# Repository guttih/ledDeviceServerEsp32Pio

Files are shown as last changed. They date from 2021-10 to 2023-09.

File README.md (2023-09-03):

# ledDeviceServerEsp32Pio
An application running on esp32 which controls a addressable light strip using
the [fastLed] library.  Supported strips are WS2811, WS2801 and  APA102.

A new program can be uploaded over the air (OTA) and controlled using [VoffCon].

## Pins
__GPIO16__ is connected to DI or Data on the strip and if the strip has
a clock pin then __GPIO17__ is connected to thi CL or Clock pin.

Some older projects use the GPIO13 and GPIO14 pins, but these pins ADC2 which
are used by the Wifi library and should not be used with wifi. 

## Development

For information intended for development of this project can be found in the
[development.adoc](docs/development.adoc) document.

[fastLed]: https://fastled.io/
[VoffCon]: http://voffcon.com/

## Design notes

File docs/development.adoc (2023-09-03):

= Development

This document contains information to help with the development of this project.

https://platformio.org/?utm_source=platformio&utm_medium=piohome[Platform IO] with the https://github.com/espressif/arduino-esp32[Arduino core for the ESP32] is used to 
compile, build, test and send the application to the https://www.espressif.com/en/products/socs/esp32[Esp32] micro controller.

[options="header"]
|====
^|Esp32 ^|Platform IO
^a|
image::https://github.com/guttih/voffcon/blob/master/docs/images/esp32DevModule.PNG?raw=true[https://github.com/guttih/voffcon/blob/master/docs/images/esp32DevModule.PNG, 160,120,link=https://www.espressif.com/en/products/socs/esp32]

^a|
Platform IO
|====

== Testing

I selected the https://docs.platformio.org/en/latest/advanced/unit-testing/frameworks/unity.html[Unity test framework] to use with https://docs.platformio.org/en/latest/advanced/unit-testing/index.html[PlatformIO] for testing specific parts of the code.

.Important links
* link:https://docs.platformio.org/page/plus/unit-testing.html[PlatformIO Unit Testing]
* link:https://docs.platformio.org/en/latest/advanced/unit-testing/frameworks/unity.html[Unity test framework]

=== Getting started with testing

. Open the Arduino IDE application 
. Find out which comport the micro-controller is connected to
.. Hover over _Tools->Port_ and remember which _COM ports_ are connected
.. Connect your Esp32 micro-controller to a usb port
.. Hover over _Tools->Port_ and remember which _COM port_ was added +
   *For demonstration purposes* set's say the port *COM6* was added.
. Set the correct test port
.. Open the file link:../platformio.ini[platformio.ini]
.. Disable uploading via wifi and enable uploading via USB
...  Make sure to add  `;` in front of the lines _upload_port = orri_sign_ and _upload_protocol = espota_ 
... Make sure that the lines lines _upload_port = COM6_ and _test_port = COM6_
   exist under the _[env:esp32dev]_ section.
... That is something like this:
+
[shell-caption]
[source, shell]
----
[env:esp32dev]
; upload_port = orri_sign
; upload_protocol = espota
upload_port = COM6
test_port = COM6
----

==== Running the test

Assuming the esp32 is connected to the usb on port COM6
```
pio test -e esp32dev
```

Showing serial print monitor
```
pio test -e esp32dev -v
```

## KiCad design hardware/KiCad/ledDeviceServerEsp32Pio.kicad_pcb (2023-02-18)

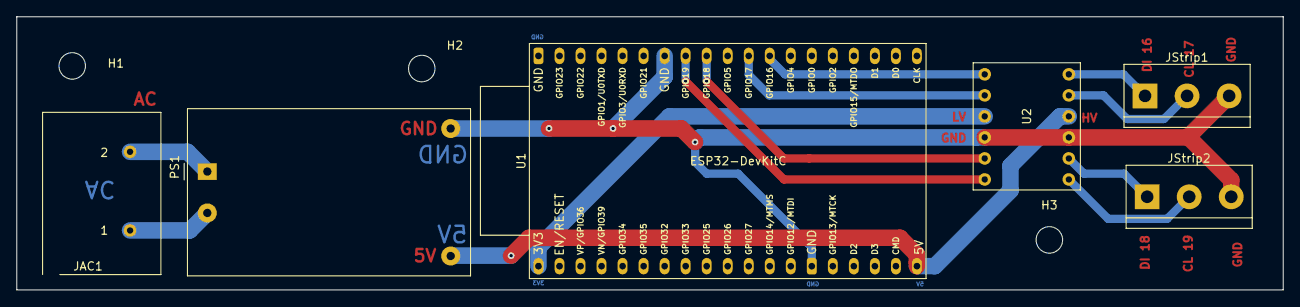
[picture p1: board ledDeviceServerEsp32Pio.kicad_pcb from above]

Board: 2 copper layers, 153.0 x 33.0 mm, 9 parts (0 on the bottom side), 13 nets.

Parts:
H1, H2, H3: MountingHole; MountingHole_3.2mm_M3
JAC1: Terminal_AC; Screw_Termianl_01x02
JStrip1, JStrip2: Terminal_LCDstrip; TerminalBlock_bornier-3_P5.08mm
PS1: HLK-PM01; Converter_ACDC_HiLink_HLK-PMxx
U1: ESP32-DevKitC
U2: LLC_4CH

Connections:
/CLOCK1: JStrip1.2, U2.7
/CLOCK2: JStrip2.2, U2.11
/DATA1: JStrip1.1, U2.5
/DATA2: JStrip2.1, U2.9
GND: JStrip1.3, JStrip2.3, PS1.3, U1.14, U1.32, U2.3
unnamed: JAC1.1, PS1.2
unnamed: JAC1.2, PS1.1
unnamed: PS1.4, U1.19, U2.2
unnamed: U1.1, U2.1
unnamed: U1.27, U2.4
unnamed: U1.28, U2.6
unnamed: U1.30, U2.8
unnamed: U1.31, U2.10

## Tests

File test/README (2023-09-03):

This directory is intended for PlatformIO Unit Testing and project tests.

Unit Testing is a software testing method by which individual units of
source code, sets of one or more MCU program modules together with associated
control data, usage procedures, and operating procedures, are tested to
determine whether they are fit for use. Unit testing finds problems early
in the development cycle.

More information about PlatformIO Unit Testing:
- https://docs.platformio.org/page/plus/unit-testing.html
- Testing this application (ledDeviceServerEsp32Pio) is described in the test section
  of the file [docs/development.adoc].

[docs/development.adoc]:../docs/development.adoc#testing

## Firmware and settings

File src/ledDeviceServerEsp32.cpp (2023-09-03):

/*
VoffCon is a system for controlling devices and appliances from anywhere.
It consists of two programs.  A "node server" and a "device server".
Copyright (C) 2016  Gudjon Holm Sigurdsson

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
You can contact the author by sending email to gudjonholm@gmail.com or
by regular post to the address Haseyla 27, 260 Reykjanesbar, Iceland.

    Program for Board: ESP32 Dev Module
*/

//Christmas lights: see: ali: https://www.aliexpress.com/item/32444415410.html?spm=a2g0s.9042311.0.0.27424c4dQ0AYL8  gparts: http://parts.guttih.com/parts/view/5bf9a0402e0e1a69a99a9bc9


//#define FASTLED_ALLOW_INTERRUPTS 0
//#define FASTLED_ESP32_FLASH_LOCK 1

/*
    To select the different strip devices you must add a define declaration
    to the file StripHelper.h
*/
#include "StripHelper.h"
#include "config.h"
#include "upload-ota.h"

#ifdef WS2811_RGB_DATA_PIN13
    const char* deviceId = "5dd9e66f67c66604d5daf0c0"; /*Hilmars ljós*/
     const char* hostName = "ws2811_strip"; /*max hostname 15 characters*/
    #define NUM_LEDS 50
    #define DATA_PIN 14  /*white wire  strip: http://parts.guttih.com/parts/register/5bf9a0402e0e1a69a99a9bc9*/
    #define STRIP_TYPE WS2811
    #define COLOR_SCHEME RGB
    StripHelper stripper;
#elif defined (CHRISTMAS_SOUTH)
    const char* deviceId = "615cabda61210d052212454d"; /*Christmas strip*/
    const char* hostName = "hilmar_strip"; /*max hostname 15 characters*/
    #define NUM_LEDS 382
    #define DATA_PIN 16  /*white wire  strip: http://parts.guttih.com/parts/view/5fa91941bff3fe05309547ee */
    #define STRIP_TYPE WS2811
    #define COLOR_SCHEME RGB
    StripHelper stripper;
#elif defined (SOLEY_IN)
    #include "StripSoley.h"
    const char* deviceId = "5c430cf9346ba80c6fe293a2"; /*Soley device*/
    const char* hostName = "soley_sign"; /*max hostname 15 characters*/
    #define NUM_LEDS 129
    #define STRIP_TYPE APA102
    #define COLOR_SCHEME BGR 
    #define CLOCK_PIN 13  
    #define DATA_PIN  14 
    StripSoley stripper; 
#elif defined (ORRI_IN)
    #include "StripOrri.h"
    const char* deviceId = "63f1253530dc6b0533d3659a"; /*Orri device*/
    const char* hostName = "orri_sign"; /*max hostname 15 characters*/
    #define NUM_LEDS 300
    #define STRIP_TYPE APA102
    #define COLOR_SCHEME BGR 
    #define CLOCK_PIN 16  
    #define DATA_PIN  17 
    StripOrri stripper; 
#elif defined (KITCHEN_ISLAND)
    const char* deviceId = "5d879b9ba02e5105340114d2"; /*Kitchen Iceland device*/    
     const char* hostName = "kitchen_island"; /*max hostname 15 characters*/
    #define NUM_LEDS 170
    #define STRIP_TYPE APA102
    #define COLOR_SCHEME BGR 
    #define CLOCK_PIN 13  /*yellow wire*/
    #define DATA_PIN  14  /*green wire*/   
    StripHelper stripper;
#else
    const char* deviceId = "5d177b6139d052053701e0af"; /*A normal strip*/
    const char* hostName = "expressif_hostN";
    #define NUM_LEDS 34 /*150 in a normal strip*/
    #define STRIP_TYPE WS2801
    #define COLOR_SCHEME RBG
    #define CLOCK_PIN 13  /*green wire*/
    #define DATA_PIN  14  /*blue wire*/ 
    StripHelper stripper;
#endif

#define BRIGHTNESS_DEVICE_PIN 15

CRGB leds[NUM_LEDS];




/*
    Board: ESP32 DEV Module
*/

// Name of the wifi (accesspoint)network
// example: "guttisWiFi"
#ifdef BLABLA
    const char* ssid = "TOTO";
#elif defined(CHRISTMAS_SOUTH)
    const char* ssid = "TOTO";
#else
    const char* ssid = "swingway"; /*This will be the default ssid used*/
#endif
// Wifi password
const char* password = getWifiPassword();
// port number which this device will be operating on.
// example: 5100
const int   PORT = 80;
// example: 6100
const int   voffconServerPort = 6100;

IPAddress

// ip address which this device will be operating on.
// Example: "192.168.1.158"     
myIp(192,168,1,238),

//the default gateway which this device will be operating on.
// example: "192.168.1.254"
gateway(192,168,1,1),

// the default gatway on this network.
// On windows goto command
// prompt and type "ipconfig"
// example: "255.255.255.0"
subnet(255,255,255,0),

// example: "192.168.1.127"
voffconServerIp(192,168,1,79);

/*boolean grantAccessToEverybody:
* Set to true if you want to allow all clients where the first 3 numbers
* in a client IP address are the same same as myIp (this server IP address).
.*/
boolean grantAccessToEveryone = false;

boolean grantAccessToAllClientsOnSameSubnet = true;
/*boolean grantAccessToFirstCaller:
* set to true if you want to allow the first client to call the "/setup" method
* to be automaticaly granted access.  that is, client IP address will be whitelisted.
.*/

WiFiServer server(PORT);

const int ERROR_NUMBER = -9999;

enum OBJECTTYPE {
    OBJECTTYPE_KEYVALUE_STRING,
    OBJECTTYPE_KEYVALUE_INT,
    OBJECTTYPE_PINS_ARRAY,
    OBJECTTYPE_PIN,
    OBJECTTYPE_PINS,
    OBJECTTYPE_DATE,
    OBJECTTYPE_WHITELIST_ARRAY,
    OBJECTTYPE_STATUS,
    OBJECTTYPE_LOG_PINS,
    OBJECTTYPE_INFORMATION,
    OBJECTTYPE_WARNING,
    OBJECTTYPE_ERROR,
    /*add next type above this line*/
    OBJECTTYPE_COUNT
};

enum JSONTYPEKEY {
    KEYVALUE_STRING,
    KEYVALUE_INT,
    KEYVALUE_DOUBLE
};

#ifndef CODE_BLOCK_LinkedList

//do not remove the comment below this line
//INSERT_FROM_HERE

//   ---------------------------------------------------------------
//  LinkedList.h - V1.1 - Generic LinkedList implementation
//  For instructions, go to https://github.com/ivanseidel/LinkedList

//  Created by Ivan Seidel Gomes, March, 2013.
//  Released into the public domain.
//   ---------------------------------------------------------------

template<class T>
struct ListNode
{
    T data;
    ListNode<T> *next;
};

/// <summary>
/// A general linked list ready to be used or Inherited
/// </summary>
template <typename T>
class LinkedList {

protected:
    int _size;
    ListNode<T> *root;
    ListNode<T> *last;

    // Helps "get" method, by saving last position
    ListNode<T> *lastNodeGot;
    int lastIndexGot;
    // isCached should be set to FALSE
    // everytime the list suffer changes
    bool isCached;

    ListNode<T>* getNode(int index);

public:
    /// <summary>
    /// The list constructor
    /// </summary>
    LinkedList();
    ~LinkedList();

    
    
    /// <summary>
    /// Returns current size of LinkedList
    /// </summary>
    /// <returns>a int number</returns>
    virtual int size();

    /// <summary>
    /// Adds a T object in the specified index;
    /// Unlinkand link the LinkedList correctly;
    /// Increment _size
    /// </summary>
    /// <param name="index">Where to add the object in the zero based index</param>
    /// <param name="T">The object to be added</param>
    /// <returns>Success: true.  Fail: false.</returns>
    virtual bool add(int index, T);

    /// <summary>
    /// Adds a T object in the end of the LinkedList;
    /// Increment _size;
    /// </summary>
    /// <param name="T">The object</param>
    virtual bool add(T);
    
    /// <summary>
    /// Adds a T object in the start of the LinkedList;
    /// Increment _size;
    /// </summary>
    /// <param name="T">The object to be added at beginning of list</param>
    /// <returns></returns>
    virtual bool unshift(T);

    /// <summary>
    /// Set the object at index, with T;
    /// Increment _size;
    /// </summary>
    /// <param name="index">Zero based index of where the object is</param>
    /// <param name="T">The object which values will be overwritten</param>
    /// <returns></returns>
    virtual bool set(int index, T);

    /// <summary>
    /// Remove object at index;
    /// If index is not reachable, returns false;
    /// else, decrement _size
    /// </summary>
    /// <param name="index"></param>
    /// <returns>Success: The object which was removed. Fail: an object created with the default constructor</returns>
    virtual T remove(int index);

    /// <summary>
    /// Remove last object;
    /// </summary>
    /// <returns>The data of the removed object</returns>
    virtual T pop();
    
    /// <summary>
    /// Remove first object;
    /// </summary>
    virtual T shift();
    
    /// /// <summary>
    /// Get the element at a specific index on the list;
    /// Return Element if accessible,
    /// else, return false;
    /// </summary>
    /// <param name="index">Zero based index if the object in the list</param>
    /// <returns>Success: the object.  Fail: A object created with a default constructor</returns>
    virtual T get(int index);

    /// <summary>
    /// Clear the entire array
    /// That is remove all objects from the list and delete them from memory
    /// </summary>
    virtual void clear();
};

// Initialize LinkedList with false values
template<typename T>
LinkedList<T>::LinkedList()
{
    root = NULL;
    last = NULL;
    _size = 0;

    lastNodeGot = root;
    lastIndexGot = 0;
    isCached = false;
}

// Clear Nodes and free Memory
template<typename T>
LinkedList<T>::~LinkedList()
{
    ListNode<T>* tmp;
    while (root != NULL)
    {
        tmp = root;
        root = root->next;
        delete tmp;
    }
    last = NULL;
    _size = 0;
    isCached = false;
}

/*
Actually "logic" coding
*/

template<typename T>
ListNode<T>* LinkedList<T>::getNode(int index) {

    int _pos = 0;
    ListNode<T>* current = root;

    // Check if the node trying to get is
    // immediately AFTER the previous got one
    if (isCached && lastIndexGot <= index) {
        _pos = lastIndexGot;
        current = lastNodeGot;
    }

    while (_pos < index && current) {
        current = current->next;

        _pos++;
    }

    // Check if the object index got is the same as the required
    if (_pos == index) {
        isCached = true;
        lastIndexGot = index;
        lastNodeGot = current;

        return current;
    }

    return NULL;
}

template<typename T>
int LinkedList<T>::size() {
    return _size;
}

template<typename T>
bool LinkedList<T>::add(int index, T _t) {

    if (index >= _size)
        return add(_t);

    if (index == 0)
        return unshift(_t);

    ListNode<T> *tmp = new ListNode<T>(),
        *_prev = getNode(index - 1);
    tmp->data = _t;
    tmp->next = _prev->next;
    _prev->next = tmp;

    _size++;
    isCached = false;

    return true;
}

template<typename T>
bool LinkedList<T>::add(T _t) {

    ListNode<T> *tmp = new ListNode<T>();
    tmp->data = _t;
    tmp->next = NULL;

    if (root) {
        // Already have elements inserted
        last->next = tmp;
        last = tmp;
    }
    else {
        // First element being inserted
        root = tmp;
        last = tmp;
    }

    _size++;
    isCached = false;

    return true;
}

template<typename T>
bool LinkedList<T>::unshift(T _t) {

    if (_size == 0)
        return add(_t);

    ListNode<T> *tmp = new ListNode<T>();
    tmp->next = root;
    tmp->data = _t;
    root = tmp;

    _size++;
    isCached = false;

    return true;
}

template<typename T>
bool LinkedList<T>::set(int index, T _t) {
    // Check if index position is in bounds
    if (index < 0 || index >= _size)
        return false;

    getNode(index)->data = _t;
    return true;
}

template<typename T>
T LinkedList<T>::pop() {
    if (_size <= 0)
        return T();

    isCached = false;

    if (_size >= 2) {
        ListNode<T> *tmp = getNode(_size - 2);
        T ret = tmp->next->data;
        delete(tmp->next);
        tmp->next = NULL;
        last = tmp;
        _size--;
        return ret;
    }
    else {
        // Only one element left on the list
        T ret = root->data;
        delete(root);
        root = NULL;
        last = NULL;
        _size = 0;
        return ret;
    }
}

template<typename T>
T LinkedList<T>::shift() {
    if (_size <= 0)
        return T();

    if (_size > 1) {
        ListNode<T> *_next = root->next;
        T ret = root->data;
        delete(root);
        root = _next;
        _size--;
        isCached = false;

        return ret;
    }
    else {
        // Only one left, then pop()
        return pop();
    }

}

template<typename T>
T LinkedList<T>::remove(int index) {
    if (index < 0 || index >= _size)
    {
        return T();
    }

    if (index == 0)
        return shift();

    if (index == _size - 1)
    {
        return pop();
    }

    ListNode<T> *tmp = getNode(index - 1);
    ListNode<T> *toDelete = tmp->next;
    T ret = toDelete->data;
    tmp->next = tmp->next->next;
    delete(toDelete);
    _size--;
    isCached = false;
    return ret;
}

template<typename T>
T LinkedList<T>::get(int index) {
    ListNode<T> *tmp = getNode(index);

    return (tmp ? tmp->data : T());
}

template<typename T>
void LinkedList<T>::clear() {
    while (size() > 0)
        shift();
}
#endif //CODE_BLOCK_LinkedList

/// <summary>
/// A list to store IP addresses
/// </summary>
class IPAddressList : public LinkedList<IPAddress*> {
private:
    void destory();
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
void loop() {
    ArduinoOTA.handle();  //todo: this causes flicker
    reconnectIfDisconnected();
    stripper.run();

    //timerTwoSeconds();
    if (monitors.isAnyPinWatchDo()) {
        // One item did trigger so you could log
        tellServerToSaveLog();
        monitors.resetAllChecks();
    }
    
    // listen for incoming clients
    WiFiClient client = server.available();
    if (client) {
        Serial.println("New client");
        memset(linebuf, 0, sizeof(linebuf));
        charcount = 0;
        // an http request ends with a blank line
        boolean currentLineIsBlank = true;
        while (client.connected()) {

            if (client.available()) {
                char c = client.read();
                Serial.write(c);
                //read char by char HTTP request
                linebuf[charcount] = c;
                if (charcount < sizeof(linebuf) - 1) charcount++;
                // if you've gotten to the end of the line (received a newline
                // character) and the line is blank, the http request has ended,
                // so you can send a reply
                if (c == '\n' && currentLineIsBlank) {

                    if (client.available() > 0) {
                        // we still got data to read, there is something after the header
                        // that is there was data after the header
                        if ((method == METHOD_POST || method == METHOD_DELETE) && contentLength > 0) {
                            //Here should contentLength == client.available()
                            for (int ix = 0; ix < contentLength; ix++) {
                                char ch = client.read();
                                linebuf[ix] = ch;
                            }
                            Serial.println(linebuf);
                            if (command == COMMANDS_POST_PINS) {
                                setPinValues(linebuf, &devicePins);
                                handlePins(&client);
                            }
                            else if (command == COMMANDS_POST_WHITELIST) {
                                if (isAuthorized(&client))
                                    whiteList.add(getKeyValueFromJsonAsString(linebuf, "ipaddress").c_str());
                                client.println(makeJsonResponseString(200, whiteList.toJson()));
                            }
                            else if (command == COMMANDS_DELETE_WHITELIST) {
                                if (isAuthorized(&client))
                                    whiteList.remove(getKeyValueFromJsonAsString(linebuf, "ipaddress").c_str());
                                client.println(makeJsonResponseString(200, whiteList.toJson()));
                            }

                        } // if (method == METHOD_POST && contentLength > 0) 
                    }
                    if (command == COMMANDS_NOTSET)
                        handleGetPinout(&client);// send a standard http response header
                    break;
                }
                if (c == '\n') {
                    // you're starting a new line
                    currentLineIsBlank = true;
                    if (strstr(linebuf, "GET /started") > 0) {
                        method = METHOD_GET;

                        Serial.println(" /started");
                        String str = "{\"date\":";
                        String itemJson = startTime.toJson();
                        str += itemJson;
                        str += "}";
                        Serial.println("time");
                        Serial.println(str);
                        client.println(makeJsonResponseString(200, str));
                        break;
                    }

                    else if (strstr(linebuf, "GET /pinout") > 0) {
                        method = METHODS::METHOD_GET;
                        handleGetPinout(&client);
                        break;
                    }
                    else if (strstr(linebuf, "GET /pins") > 0) {
                        handlePins(&client);
                        break;
                    }
                    else if (strstr(linebuf, "GET /status") > 0) {
                        handleStatus(&client);
                        break;
                    }
                    else if (strstr(linebuf, "GET /monitors") > 0) {
                        handleMonitors(&client, METHODS::METHOD_GET);
                        break;
                    }
                    else if (strstr(linebuf, "POST /monitors") > 0) {
                        handleMonitors(&client, METHODS::METHOD_POST);
                        break;
                    }
                    else if (strstr(linebuf, "DELETE /monitors") > 0) {
                        handleMonitors(&client, METHODS::METHOD_DELETE);
                        break;
                    }
                    else if (strstr(linebuf, "GET /custom") > 0) {
                        handleCustom(&client, METHODS::METHOD_GET, linebuf);
                        break;
                    }
                    else if (strstr(linebuf, "POST /custom") > 0) {
                        handleCustom(&client, METHODS::METHOD_POST, linebuf);
                        break;
                    }
                    else if (strstr(linebuf, "DELETE /custom") > 0) {
                        handleCustom(&client, METHODS::METHOD_DELETE, linebuf);
                        break;
                    }
                    else if (strstr(linebuf, "POST /pins") > 0) {
                        method = METHODS::METHOD_POST;
                        command = COMMANDS::COMMANDS_POST_PINS;
                    }
                    else if (strstr(linebuf, "POST /whitelist") > 0) {
                        method = METHODS::METHOD_POST;
                        command = COMMANDS::COMMANDS_POST_WHITELIST;
                    }
                    else if (strstr(linebuf, "DELETE /whitelist") > 0) {
                        method = METHODS::METHOD_DELETE;
                        command = COMMANDS::COMMANDS_DELETE_WHITELIST;
                    }
                    else if (strstr(linebuf, "Content-Length: ") > 0) {
                        String strTemp = String(strstr(linebuf, "Content-Length: ") + 16);
                        strTemp.replace("\r", ""); strTemp.replace("\n", "");
                        contentLength = GTime::toNumber(strTemp);
                    }

                    // you're starting a new line
                    currentLineIsBlank = true;
                    memset(linebuf, 0, sizeof(linebuf));
                    charcount = 0;
                }
                else if (c != '\r') {
                    // you've gotten a character on the current line
                    currentLineIsBlank = false;
                }
            }//if (client.available())
        }//while (client.connected()) 
        
        // give the web browser time to receive the data
        delay(1);
        // close the connection:
        method = METHODS::METHOD_NOTSET;
        command = COMMANDS::COMMANDS_NOTSET;
        client.stop();
        contentLength = 0;
        Serial.println("client disconnected");
    }
}
///////////////////////////////////// IMPLEMENTATION OF ALL CLASSES  /////////////////////////////////////

#ifndef CODE_BLOCK_IPAddressList

/// <summary>
/// The deconstructor, which cleans up when the list is no longer needed.
/// </summary>
IPAddressList::~IPAddressList() { 
    destory();
}

/// <summary>
/// Add an ip address to the list by providing a string with a valid IP address
/// </summary>
/// <param name="strIpAddress">
///     a string with a valid IP address.  
///     The ip address "0.0.0.0" will be considered as an invalid ipaddress
/// </param>
/// <returns>True if the add succeded, otherwise false</returns>
bool IPAddressList::add(const char *strIpAddress) {
    IPAddress *p = new IPAddress();
    p->fromString(strIpAddress);
    if (*p == IPAddress(0, 0, 0, 0) || exists(*p)) {
        delete p;
        return false; //we will not allow "0.0.0.0"
    }
    return LinkedList<IPAddress*>::add(p);
}

/// <summary>
/// Add an ip address by providing four numbers of the IP addres each in the range of 0 - 255
/// </summary>
/// <param name="first_octet">First number of the ip address </param>
/// <param name="second_octet">Second number of the ip address</param>
/// <param name="third_octet">Third number of the ip address </param>
/// <param name="fourth_octet">Fourth number of the ip address</param>
bool IPAddressList::add(uint8_t first_octet, uint8_t second_octet, uint8_t third_octet, uint8_t fourth_octet) { 
    return add(IPAddress(first_octet, second_octet, third_octet, fourth_octet)); 
};
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

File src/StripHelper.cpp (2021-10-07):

#include "StripHelper.h"

StripHelper::StripHelper() {
    init();
}

void StripHelper::initialize(CFastLED *controller) {
    this->fastLED = controller;
    leds = fastLED->leds();
    ledCount = fastLED->size();
}

CFastLED *StripHelper::getController() {
    return this->fastLED;
}

void StripHelper::fillByIndex(int startIndex, int endIndex, const struct CRGB& color){
    for(int i = startIndex; i<endIndex+1; i++){
         leds[i] = color;
    }
}

void StripHelper::init() {
    ledCount = 0;
    tempArray = NULL;
    reset();

}

void StripHelper::reset() {
    ulWorker1 =0;
    iWorker1 = 0;
    lightLastTime =0;
    step = 0;
    turns = 0;
    direction = 1;
    stepDelay = 0;
    byteWorker1 = 0;
    value1 = 0;
    value2 = 0;
    value3 = 0;
    stripMustBeOff = false;
    brightness = 1;
    program = STRIP_PROGRAMS::SINGLE_COLOR;
    stripColors[0] = CRGB::Magenta;
    stripColors[1] = CRGB::Red;
    stripColors[2] = CRGB::Green;
    stripColors[3] = CRGB::Blue;
    stripColors[4] = CRGB::White;
    stripColors[5] = CRGB::Brown;

    if (tempArray != NULL) {
        delete [] tempArray;
        tempArray = NULL;
    }
}

void StripHelper::setNewValues(STRIP_PROGRAMS program, unsigned long stepDelay, unsigned long value1, unsigned long value2, unsigned long value3){
    this->program   = program;
    this->stepDelay = stepDelay;
    this->value1    = value1;
    this->value2    = value2;
    this->value3    = value3;
    Serial.print("Program:");Serial.print(program);
    Serial.print(" | stepDelay:");Serial.print(stepDelay);
    Serial.print(" | value1:");Serial.print(value1);
    Serial.print(" | value2:");Serial.println(value2);
    Serial.print(" | value3:");Serial.println(value3);
}

//will reverse current direction set turns to 0
//if new direction is forward  then step will be set to first pixel index
//if new direction is backward then step will be set to the last pixel index
void StripHelper::toggleDirection() {
    step = 0;
    turns = 0;
    bool directionForward = direction == 1? false : true;
    if (!directionForward){
        direction = -1;
        step = getLast();    
    } else 
    direction = 1;
}

// returns true if step had to be fixed
//return false if step was ok;

bool StripHelper::fixStep() {
    if (step >= ledCount){
        step = 0;
        turns++;
        return false;
    } else if (step < 0) {
        turns--;
        step = ledCount -1;
        return false;
    }
    return true;
}

// Increments the step and returns the incremented step
int StripHelper::stepUp() {
    step+=direction;
    fixStep();
    return step;
}

// Decrements the step and returns the decremented step
int StripHelper::stepDown() {
    step+=direction*-1;
    fixStep();
    return step;
}

int StripHelper::getCount() {
    return ledCount;
}


//if index out of bounds Black is returned
CRGB StripHelper::getColorBank(uint8_t index){
    if (index >= COLOR_COUNT)
        return CRGB::Black;
    return stripColors[index];
}

bool StripHelper::setColorBank(uint8_t index, CRGB newColor){
    if (index >= COLOR_COUNT)
        return false;
    stripColors[index] = newColor;
    return true;

}

int StripHelper::getLast() {
    return ledCount -1;
}

int StripHelper::getStep() {
    return step;
}

int StripHelper::getTurns() {
    return turns;
}

unsigned long StripHelper::getStepDelay() {
    return stepDelay;
}
STRIP_PROGRAMS StripHelper::getProgram() {
    return program;
}

//if step was set the return is true
//if step was out of bounds and had to be fixed then return is false
bool StripHelper::setStep(int newStep) {
    step = newStep;
    return !fixStep();
}

void StripHelper::setBrightness(uint8_t brightness) {
    this->brightness = brightness;
}

uint8_t StripHelper::getBrightness() {
    return brightness;
}


int StripHelper::getDirection() {
    return direction;
}

// if forward is true then direction is forward
// if forward is true then direction is backward
int StripHelper::setDirection(bool forward) {
    direction = forward? 1 : -1;
}

String StripHelper::getProgramName(STRIP_PROGRAMS stripProgram) {

    switch(stripProgram){
        case OFF            : return "Off";
        case RESET          : return "Reset";
        case SINGLE_COLOR   : return "Single color";
        case MULTI_COLOR    : return "Multicolor";
        case UP             : return "Up";
        case DOWN           : return "Down";
        case UP_DOWN        : return "Up and down";
        case RAINBOW        : return "Rainbow";
        case CYLON          : return "Cylon";
        case STARS          : return "Stars";
        case SECTIONS       : return "Sections";
        
#ifdef SOLEY_IN    
        case SOLEY          : return "SOLEY";
#endif
    }
    return "Invalid program";
}

String StripHelper::getProgramDescription(STRIP_PROGRAMS stripProgram) {

    switch(stripProgram){
        case OFF            : return "Turns the strip off";
        case RESET          : return "resets all strip values.  Like turning the strip off, and then on again without ever loosing Wifi connection.";
        case SINGLE_COLOR   : return "First color will be set to all of the strip pixels";
        case MULTI_COLOR    : return "Display each of your selected colors in series through out the strip.";
        case UP             : return "Color 0 is the color of a a pixel running up the strip. Color 1 is the background.";
        case DOWN           : return "Color 0 is the color of a a pixel running down the strip. Color 1 is the background.";
        case UP_DOWN        : return "Color 0 is the color of a a pixel running up and down the strip. Color 1 is the background.";
        case STARS          : return "Color 0 is the color of a start pixel.  Color 1 is the background color.";
        case RAINBOW        : return "There is no change if both values 0.  Try changing them to figure out what you like.  The program is very versatile. Test and see :)";
        case CYLON          : return "Multiple color will flow down the strip.";
        case SECTIONS       : return "Dived the strip to 4 color sections.  Possbile colors are from 0-4. Color 0 is for section 1, color 1 is for section 2 and so on.";
#ifdef SOLEY_IN            
        case SOLEY          : return "Color 0 will be set to underline.  Color 1 will be set to S.  Color 2 will be set to O.  Color 3 will be set to L.  Color 4 will be set to E.  Color 5 will be set to Y.";
#endif        
    }
    return "This program is one of the available program.  The possible programs are only from 0 to " + String(((int)STRIP_PROGRAMS::STRIP_PROGRAMS_COUNT)-1) + ".";
}
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

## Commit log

2021-10-07 Activating upload program wirelessly (OTA)
2021-10-07 Reducing flickering because of ArduinoOTA.handle
2021-11-17 Adding Hardware folder for KiCad Project
    [ledDeviceServerEsp32Pio.kicad_pcb, ledDeviceServerEsp32Pio.sch]
2021-11-18 KiCad Schematic done
    [ledDeviceServerEsp32Pio.sch]
2021-11-18 removing file ledDeviceServerEsp32Pio-cache.lib
2021-11-18 pcb done
    [ledDeviceServerEsp32Pio.kicad_pcb, ledDeviceServerEsp32Pio.sch]
2021-11-23 Printed one board
    [ledDeviceServerEsp32Pio-B_Cu.gbr, ledDeviceServerEsp32Pio-B_SilkS.gbr, ledDeviceServerEsp32Pio-Edge_Cuts.gbr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]
2021-11-25 drawing and wiring
2021-12-24 Adding text on plugs
    [ledDeviceServerEsp32Pio-B_Cu.gbr, ledDeviceServerEsp32Pio-B_SilkS.gbr, ledDeviceServerEsp32Pio-Edge_Cuts.gbr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]
2021-12-24 This was produced, zipped and sent to jlcpcb.com
    [ledDeviceServerEsp32Pio-B_Cu.gbr, ledDeviceServerEsp32Pio-B_Mask.gbr, ledDeviceServerEsp32Pio-B_SilkS.gbr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]
2023-02-18 adding long-pcb
    [ledDeviceServerEsp32Pio-B_CrtYd.gbr, ledDeviceServerEsp32Pio-B_Cu.gbr, ledDeviceServerEsp32Pio-B_Mask.gbr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]
2023-02-19 removing printHeapSize
2023-02-22 fixing hostname in orri
    [ledDeviceServerEsp32.cpp]
2023-09-03 setting maximum power to 5v and 7amps

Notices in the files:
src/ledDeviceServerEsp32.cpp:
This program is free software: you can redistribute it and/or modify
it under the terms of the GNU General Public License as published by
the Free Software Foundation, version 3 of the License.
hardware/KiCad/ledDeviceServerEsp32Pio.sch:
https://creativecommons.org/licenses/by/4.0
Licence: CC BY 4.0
